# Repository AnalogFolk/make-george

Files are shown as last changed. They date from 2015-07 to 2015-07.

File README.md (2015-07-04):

# MAKE: George (the talking plant)

MAKE George the talking plant

**Overview**  
Imagine if you could talk to your house plants and they would tell you if they needed water, how hot it was and even look at you as you walk past...  

George is an experimental prototype to explore how easy it is to mix [Arduino](https://www.arduino.cc/), [Socket.io](http://socket.io/) and the [HTML5 Web Speech API](https://dvcs.w3.org/hg/speech-api/raw-file/tip/speechapi.html) (Speech & Synthesis) to do just that.

An article about George can be found on the [AnalogFolk MAKE website](http://make.analogfolk.com/george-the-talking-plant/). This repo contains the code and steps to set up your very own George.

**How it works**  
There are 3 main parts to George:

1. Aurdino application: *Written in C++ to output the data from the sensors*
2. Socket.io script: *Reads and broadcasts the sensor data as JSON*
3. HTML5 script: *Reads the data excutes speech recognition and speech synthesis using the [HTML5 Web Speech API](https://dvcs.w3.org/hg/speech-api/raw-file/tip/speechapi.html)*

## Hardware requirements

A George MAKE kit can be [purchased from ETSY](http://anfo.lk/buygeorge).

Alternatively you can source your own hardware from the list below (*but we can't guarantee the code will work with parts you source yourself*):

* LM35 Temp Sensor
* Soil Hygrometer Humidity Detection
* PIR Motion Sensor
* MAX7219 8x8 LED Dot Matrix Display
* Light Sensor
* Arduino Uno

## Software requirements/dependencies

* Node
* Serialport
* Socket.io
* Express
* Crypto

## Installation & Usage

**Wiring diragram:**  
Wire up the hardware components as follows:
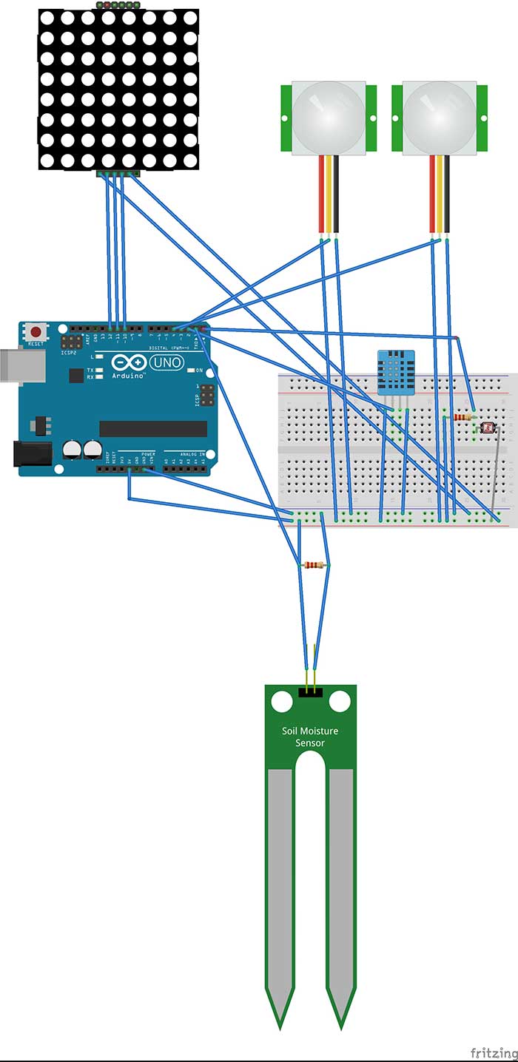
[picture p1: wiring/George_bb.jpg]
Wiring diagram


**Step by step:**  

1. Fork the repo
2. NPM install to install node dependencies
3. Wire up George as above (you can also work out wiring by reading the sensor_read.ino)
4. Upload the sensor_read.ino to the Arduino Uno using the Arduino IDE
5. Run node index.js and visit http://localhost:8000 to interact with George

## Contributing

1. Folking fork it!
2. Create your feature branch: `git checkout -b my-new-feature`
3. Commit your changes: `git commit -am 'Add some feature'`
4. Push to the branch: `git push origin my-new-feature`
5. Submit a pull request :D

## Credits

A [MAKE](http://make.analogfolk.com) project hacked together by Mate Marschalko ([@MateMarschalko](https://twitter.com/MateMarschalko)) at [AnalogFolk](http://analogfolk.com) ([@analogfolk](https://twitter.com/analogfolk)).

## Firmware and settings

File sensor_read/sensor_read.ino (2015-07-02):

  // Characters
   
  byte happy[8]={
    B00000000,
    B00100110,
    B01000110,
    B01000000,
    B01000000,
    B01000110,
    B00100110,
    B00000000
  };
  
  byte happyL[8]={
    B00000000,
    B00100110,
    B01000000,
    B01000000,
    B01000000,
    B01000110,
    B00100000,
    B00000000
  };
  
  byte happyR[8]={
    B00000000,
    B00100000,
    B01000110,
    B01000000,
    B01000000,
    B01000000,
    B00100110,
    B00000000
  };
   
  byte sad[8]={
    B00000000,
    B01000110,
    B00100110,
    B00100000,
    B00100000,
    B00100110,
    B01000110,
    B00000000
  };
  
  byte sadL[8]={
    B00000000,
    B01000110,
    B00100000,
    B00100000,
    B00100000,
    B00100110,
    B01000000,
    B00000000
  };
  
  byte sadR[8]={
    B00000000,
    B01000000,
    B00100110,
    B00100000,
    B00100000,
    B00100000,
    B01000110,
    B00000000
  };
  
  byte over[8]={
    B00000000,
    B00100110,
    B01010110,
    B01010000,
    B01010000,
    B01010110,
    B00100110,
    B00000000
  };

  byte dying[8]={
    B00000000,
    B00000100,
    B10000100,
    B01000000,
    B01000000,
    B10000100,
    B00000100,
    B00000000
  };
  
#include <OneWire.h>
OneWire  ds(2);
float fahrenheit, celsius;

void calculateTemp(){
  byte i;
  byte present = 0;
  byte type_s;
  byte data[12];
  byte addr[8];
    
  if ( !ds.search(addr)) {
    ds.reset_search();
    delay(1000);
    return;
  }
  
  if (OneWire::crc8(addr, 7) != addr[7]) {
      return;
  }
   
  switch (addr[0]) {
    case 0x10:
      type_s = 1;
      break;
    case 0x28:
      type_s = 0;
      break;
    case 0x22:
      type_s = 0;
      break;
    default:
      Serial.println("Device is not a DS18x20 family device.");
      return;
  }
  
  ds.reset();
  ds.select(addr);
  ds.write(0x44,1);
    
  delay(1000);
    
  present = ds.reset();
  ds.select(addr);   
  ds.write(0xBE);         // Read Scratchpad
  
  for ( i = 0; i < 9; i++) {           // we need 9 bytes
    data[i] = ds.read();
  }
  
  // convert the data to actual temperature
  unsigned int raw = (data[1] << 8) | data[0];
  if (type_s) {
    raw = raw << 3; // 9 bit resolution default
    if (data[7] == 0x10) {
      // count remain gives full 12 bit resolution
      raw = (raw & 0xFFF0) + 12 - data[6];
    }
  } else {
    byte cfg = (data[4] & 0x60);
    if (cfg == 0x00) raw = raw << 3;  // 9 bit resolution, 93.75 ms
    else if (cfg == 0x20) raw = raw << 2; // 10 bit res, 187.5 ms
    else if (cfg == 0x40) raw = raw << 1; // 11 bit res, 375 ms
    // default is 12 bit resolution, 750 ms conversion time
  }
  celsius = (float)raw / 16.0;
  fahrenheit = celsius * 1.8 + 32.0;
}
 
#include "LedControlMS.h"
LedControl lc=LedControl(12,11,10,1);
 
void draw(byte h[]){
  lc.setRow(0,0,h[0]);
  lc.setRow(0,1,h[1]);
  lc.setRow(0,2,h[2]);
  lc.setRow(0,3,h[3]);
  lc.setRow(0,4,h[4]);
  lc.setRow(0,5,h[5]);
  lc.setRow(0,6,h[6]);
  lc.setRow(0,7,h[7]);
}

// PINS
int motion1_pin = 3;
int motion2_pin = 4;
int soil_pin = 0;
int light_pin = 1;

// VALUES
int motion1_val = 0;
int motion2_val = 0;
int soil_val = 0;
int light_val = 0;

void setup(){
  pinMode(motion1_pin, INPUT);
  pinMode(motion2_pin, INPUT);
  
  // LCD wakeup
  lc.shutdown(0,false);
  // LCD brightness
  lc.setIntensity(0,1);
  // LCD clear display
  lc.clearDisplay(0);
  
  Serial.begin(9600);
}

void loop(){
  motion1_val = digitalRead(motion1_pin);
  motion2_val = digitalRead(motion2_pin);
  soil_val = map(analogRead(soil_pin), 0, 1023, 100, 0);
  light_val = map(analogRead(light_pin), 0, 512, 100, 0);
  
  calculateTemp();

  if(soil_val < 25 || celsius > 30 || celsius < 15) {
    draw(dying);
  } else if(soil_val > 75) {
    draw(over);
  } else if(light_val >= 30 && soil_val >= 66 && celsius >= 18 && celsius <= 26) {
    if(motion1_val == 1 && motion2_val == 0) {
      draw(happyL);
    } else if(motion1_val == 0 && motion2_val == 1) {
      draw(happyR);
    } else {
      draw(happy);
    } 
  } else {
    if(motion1_val == 1 && motion2_val == 0) {
      draw(sadL);
    } else if(motion1_val == 0 && motion2_val == 1) {
      draw(sadR);
    } else {
      draw(sad);
    } 
  }
  
  // form a JSON-formatted string:
  String jsonString = "{\"motion1\":\"";
  jsonString += motion1_val;
  jsonString +="\",\"motion2\":\"";
  jsonString += motion2_val;
  jsonString +="\",\"moisture\":\"";
  jsonString += soil_val;
  jsonString +="\",\"light\":\"";
  jsonString += light_val;
  jsonString +="\",\"temperature\":\"";
  jsonString += int(celsius);
  jsonString +="\"}";

  // print it:
  Serial.println(jsonString);
  
}

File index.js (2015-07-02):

//	Simple HTTP server
//	var serialport = require("serialport"),
//		SerialPort = serialport.SerialPort,
//		express = require('express'),
//		app = express(),
//		server = require('http').createServer(app).listen(8080),    
//		io = require('socket.io').listen(server);


// Library includes
var fs = require('fs'),
	express = require('express'),
	app = express(),
	https = require('https'),
	io = require('socket.io'),
	serialport = require("serialport"),
	SerialPort = serialport.SerialPort;

// SSH keys
var key = fs.readFileSync('key.pem'),
	cert = fs.readFileSync('cert.pem')
	https_options = {
	    key: key,
	    cert: cert
	};

// Server settings
var	PORT = 8000,
	HOST = 'localhost',
	USB  = '/dev/tty.usbmodem1411';

//
// Start HTTPS server with socket.io
server = https.createServer(https_options, app).listen(PORT, HOST);
io = io.listen(server);

console.log('HTTPS Server listening on %s:%s', HOST, PORT);

//
// Open USB  port
var myPort = new SerialPort(USB, { 
	// look for return and newline at the end of each data packet
	parser: serialport.parsers.readline("\r\n")
});

var connected = false;

//  
// Respond to web GET requests with index.html page:
app.get('/', function (request, response) {
	response.sendfile(__dirname + '/index.html');
});

//
// Define route folder for static requests
app.use(express.static(__dirname + '/'));

//
// Listen for new socket.io connections when browser connected
io.sockets.on('connection', function (socket) {

	if (!connected) {
		// clear out any old data from the serial bufffer:
		myPort.flush(function(){});
		// send a byte to the serial port to ask for data:
		myPort.write('c');
		console.log('browser connected');
		connected = true;
	}

	// Handle client disconnect:
	socket.on('disconnect', function () {
		myPort.write('x');
		console.log('browser disconnected');
		connected = false;
	});

	//
	// Listen for new serial data
	myPort.on('data', function (data) {
		// Convert the string received into a JSON object:
		var serialData = tryParseJSON(data);
		// send a serial event to the web client with the data:
		socket.emit('serialEvent', serialData);
	});
});

function tryParseJSON (jsonString){
	try {
		var o = JSON.parse(jsonString);
		if (o && typeof o === "object" && o !== null) {
			return o;
		}
	}
	catch (e) { }
	return false;
};
